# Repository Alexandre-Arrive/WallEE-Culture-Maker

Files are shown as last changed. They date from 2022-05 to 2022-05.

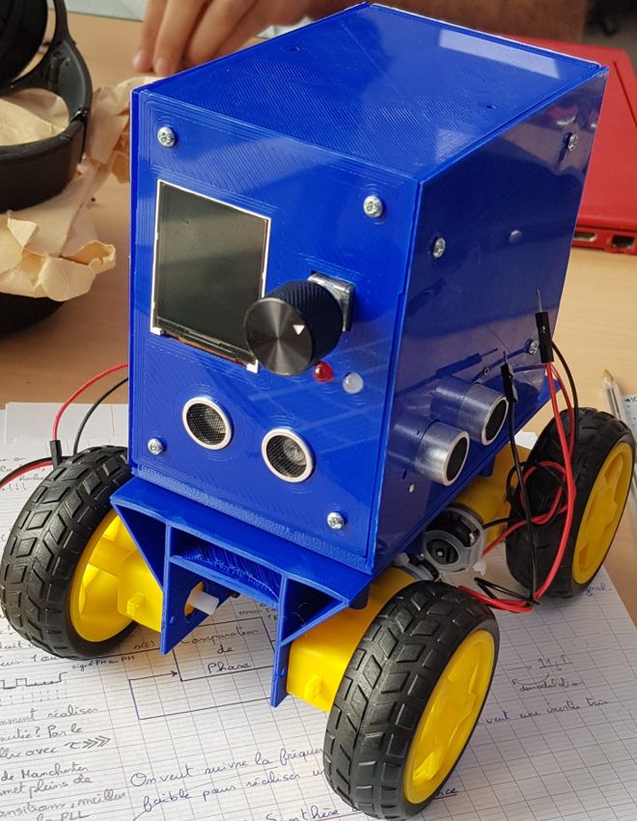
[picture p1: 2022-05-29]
wallee_outside_image.PNG

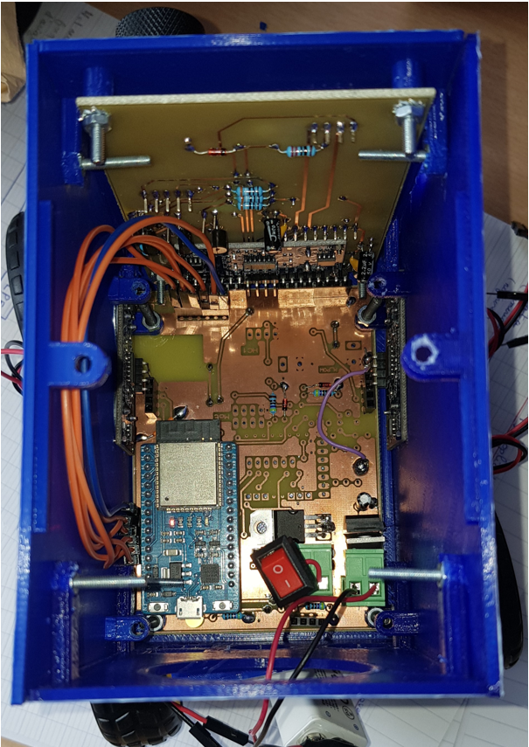
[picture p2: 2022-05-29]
wallee_inside_image.PNG

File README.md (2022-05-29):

Repositery du projet Culture Maker "WallEE".

Projet réalisé par Valentin Romero, Alexandre Arrivé, Mathieu Bernard
ENSEIRB-MATMECA, Département Electronique, 2022

Notre objectif était de concevoir un robot autonome capable détecter les obstacles dans son environnement, de se déplacer, de générer du son, et de proposer une interface utilisateur intuitive.

Le projet est donc composé d'une partie modélisation 3D, d'une partie circuit éléctronique, et d'une partie programmation.

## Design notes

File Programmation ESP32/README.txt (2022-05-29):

Ce dossier contient l'ensemble de nos codes permettant de vérifier le bon fonctionnement du robot.

La programmation de l'ESP32 est réalisée à l'aide de l'IDE Arduino.

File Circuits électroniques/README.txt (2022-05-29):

Ce dossier permet d'accéder aux différents circuits électroniques du projet.

Les deux fichiers principaux sont "PCB_central" et "PCB_face_avant".

Des images sont disponibles pour comprendre les circuits, sinon il sont ouvrables avec Proteus 8.

Les différentes parties disposent très souvent de fichier .doc qui permettent de détailler le fonctionnement des parties.

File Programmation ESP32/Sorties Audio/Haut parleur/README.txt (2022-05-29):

Ce code ne fonctionne que sur Arduino, il faut le porter sur l'ESP32.
Le problème vient de la lecture des données de la carte SD depuis l'ESP.

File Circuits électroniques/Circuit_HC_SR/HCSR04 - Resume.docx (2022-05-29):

# Résumé HCSR04 x4

I- HC-SR-04
1) La tension d’alimentation est 5V
2) La communication est 5V. On vient ajuster les tensions à l’aide d’un circuit.
3) Code + Circuit

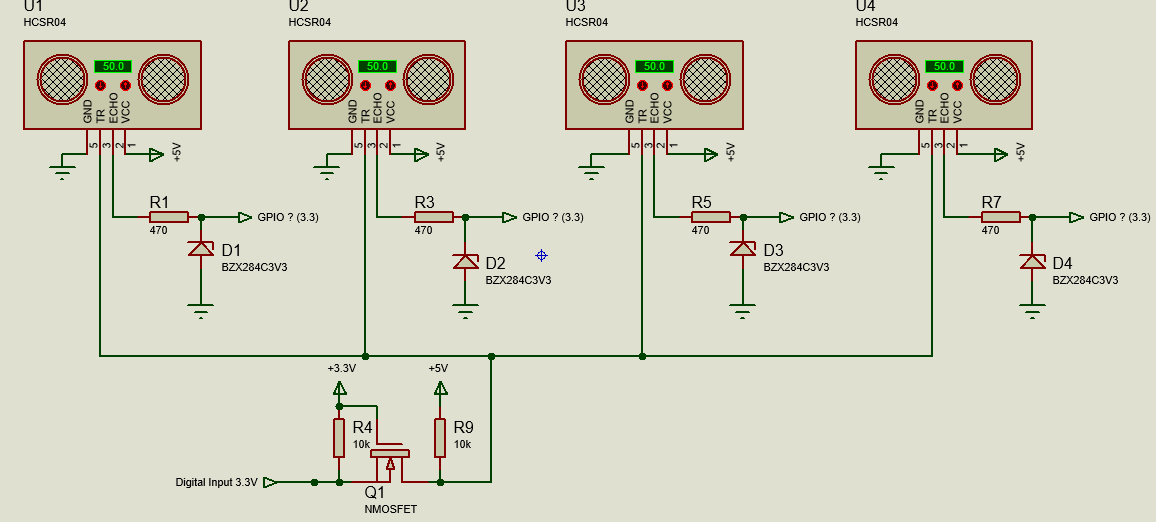
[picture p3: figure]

Code d’exemple « HC-SR-04-Wallee.ino » (avec fonctions générales)

Code propre pour utilisation sur programme final : « HC-SR-04-wallee-propre »

Code de temps d’éxecution « HCSR -temps-execution.ino » (programme de temps d’éxecution)

4) Principe de fonctionnement

Ecriture à l’état haut sur le trigger (commun à tous les capteurs) : émission 8 signaux ultrasons, on peut alors lire le capteur qui renvoi une durée d’impulsion (echo) qui détermine la distance parcourue.

Super article : https://www.gotronic.fr/pj2-hc-sr04-utilisation-avec-picaxe-1343.pdf

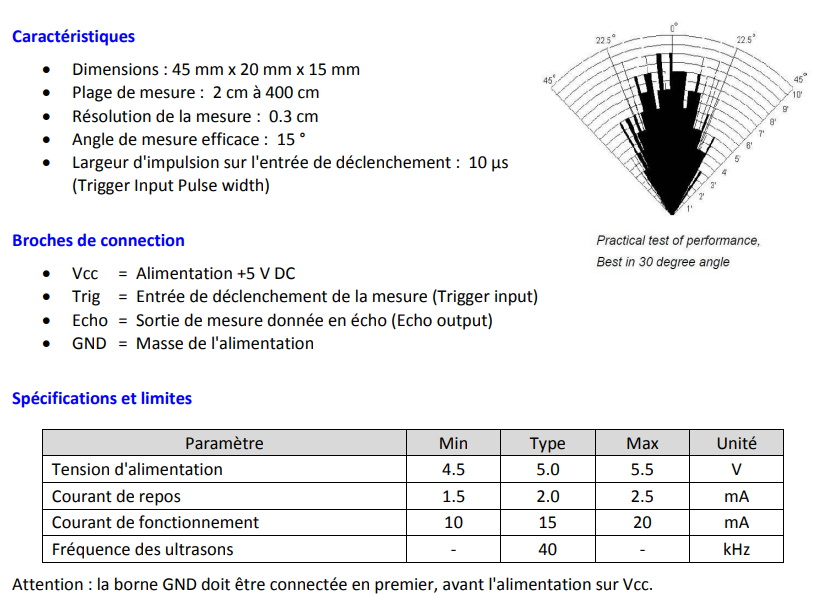
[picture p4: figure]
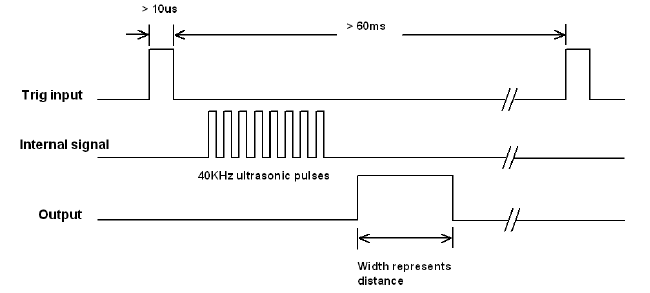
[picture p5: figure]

5) Pins

1- +5V | +5V
2- Trig | 26 (ESP) 5 (ARDUINO)
3- Echo | 35,34,39,36 (ESP) 6, 7, 8, 9 (ARDUINO)
4- GND | GND

Librairies à utiliser

#include <HCSR04.h>

Initialisation HC-SR04 x4(ARDUINO)

#define HC_trig 26 //On définit les broches des capteurs

#define HC1 35

#define HC2 34

#define HC3 39

#define HC4 36

HCSR04 hc_front(HC_trig, HC1); //On crée 4 objets correspondants aux capteurs

HCSR04 hc_right(HC_trig, HC2);

HCSR04 hc_left (HC_trig, HC3);

HCSR04 hc_back (HC_trig, HC4);

int erreur_ultrason=0; //Nombre d’erreur de mesure

int lim_err_HC=5; //Limite d'erreur avant reset des capteurs

int front=0; int right=1; int left=2; int back=3; //Rend intuitif l’appel des fonction: « ultrason_read(right) »

int measure_time=60; //Délai entre 2 mesures, recommandé à 60ms

int decharge_time=100; //Délai pour décharger les capteurs à l’initialisation/si trop d’erreur

Initialisation LED (ARDUINO)

#define led_verte 32

#define led_rouge 33

#define led_blanche 25

Fonctions à utiliser

Nom fonction | Rôle | Pire temps d’exécution (déconnecté) | Meilleur temps d’exécution
void Ultrason_Setup() | Setup des 4 capteurs | 120ms/120ms | 100ms
double Ultrason_Read(front/left/right/back) | Lecture distance 1 capteur | 199ms/1120ms | 1ms
int Ultrason_Indication(front/left/right/back) | Lecture indication 1 capteur | 199ms/1120ms | 1ms
double* Ultrason_All_Read() | Lecture distance 4 capteurs | 2318ms/4180ms | 184ms
int* Ultrason_All_Indication () | Lecture indication 4 capteur | 1517ms/4300ms | 184ms
void ultrason_ERREUR() | Réinitialise les capteurs + allume LED verte et rouge (commandé par Indication) | 125ms/125ms | 120ms

Fonction Setup - Fonction à utiliser – Fonction interne/peu probable à utiliser

NOTE IMPORTANTE –

Après avoir utilisé « Ultrason_All_Read() » il faut « delete distante » pour libérer l’espace mémoire

Après avoir utilisé « Ultrason_All_Indication » il faut « delete indication » pour libérer l’espace mémoire.

Il faut espacer deux mesures sur un même capteur de 60ms ! C’est la variable « measure_time ».

Les fonctions « Ultrason_Read » et « Ultrason_All_Read » ne peuvent pas lancer la fonction d’erreur automatiquement. Seules les fonctions « Ultrason_Indication » et « Ultrason_All_Indication » le font.

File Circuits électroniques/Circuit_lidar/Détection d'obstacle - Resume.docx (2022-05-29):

# Résumé détection d’obstacle

I- Lidar TF-Luna – I2C
1) La tension d’alimentation est 5V
2) La tension de communication est 3.3V – I2C (adresse 0x10)
3) Code + Circuit

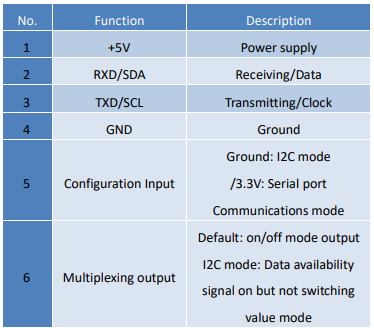
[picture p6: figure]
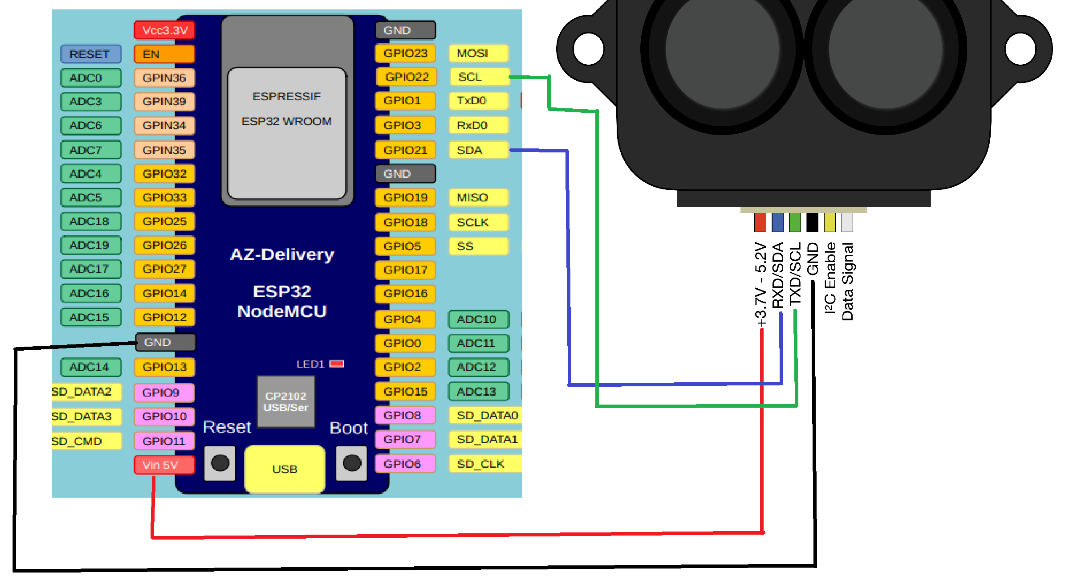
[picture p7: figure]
Issues with I2C communication for TFLuna LiDAR sensor from benewake: : r/esp32

Code d’exemple « LUNA-TEST-I2C.ino » (sans modification)

Code d’exemple « LUNA-I2C.ino » (avec fonctions générales)

Code de temps d’éxecution « LUNA-temps-execution.ino » (programme de temps d’éxecution)

4) Ecriture des fonctions pour le programme général

Initialisation

TFLI2C luna; //crée un objet TF-Luna appelé « luna »

int16_t tfAddr = TFL_DEF_ADR; // default I2C address – uint8_t

uint16_t tfFrame = TFL_DEF_FPS; // default frame rate

Setup

Wire.Begin() ;

luna.Soft_Reset(adr) // Reset, reboot et restart

if ( luna.Soft_Reset(adr) ) { LUNA_OK } //Détection d’erreur provenant du TF Luna

else luna.printStatus() ; //permet de connaitre l’état du TF Luna

luna.Get_Time( tfTime, adr); //Horloge du TF Luna sur un entier 16 bits

luna.Set_Frame_Rate( tfFrame, adr) ; //Envoie le nombre de frame/s, entier 16 bits

tfFrame = FPS_1 2 3 4 5 6 7 8 9 10 35 50 100 125 250 ou TFL_DEF_FPS=100

luna.Get_Frame_Rate( tfFrame, adr) ; // Lecture du nombre de frame/s

luna.Set_Trig_Mode(adr) ; //Mode trigger du Luna

luna.Set_Cont_Mode(adr) ; //Mode continu du Luna

luna.Save_Settings(adr) ; //Nécessaire après avoir changé le Frame-rate ou le Trig/Cont_Mode ou

l’adresse I2C

luna.Set_I2C_Addr(new adr, adr) ; //Permet de changer l’adresse I2C du Luna

Acquisition

luna.getData(dist, flux, temp, adr) ; //Lit le Luna et change la valeur de la distance, du flux et de la

température qui sont des entier signés 16 bits.

Il faut diviser la température reçue par 100.

La fonction renvoie 0 si la mesure s’est bien passé (si l’adresse I2C de retour est OK), on doit faire if( GetData){ affectation des mesures } Else { réagir au problème }

luna.getData(dist, adr) ; //Comme précédemment mais seulement pour la distance

5) Pins

1- +5V | +5V
2- SDA | 21
3- SCL | 22
4- GND | GND
5- Config I2C/Uart | GND
6- Multiplex output | rien

Librairies à utiliser

#include <Arduino.h> | #include <Wire.h> | #include <TFLI2C.h>

Initialisation TF-Luna

TFLI2C luna;

int16_t luna_addr = TFL_DEF_ADR;

uint16_t luna_frame = FPS_35;

int16_t luna_dist = 0 ;

int16_t luna_flux = 0 ;

int16_t luna_temp = 0 ;

Initialisation LED

#define led_verte 32

#define led_rouge 33

bool vert = HIGH;

Fonctions à utiliser

Nom fonction | Rôle | Pire temps d’exécution | Meilleur temps d’exécution
Luna_Setup() | Setup du TF-Luna | 42ms/62ms | 23ms
Luna_Measure() | Mesure de la distance, flux, et température | 23ms | 20ms/3ms
Luna_OK() | Inverse l’état de la LED verte | <1ms | <1ms
Luna_ERREUR() | Allume la LED rouge pendant 20ms | 21ms | 20ms

Fonction Setup - Fonction à utiliser – Fonction interne/peu probable à utiliser

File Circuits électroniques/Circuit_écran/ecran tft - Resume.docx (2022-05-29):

# Ecran tft

1) La tension d’alimentation est 5V
2) La communication s’effectue en 5V
3) Code + Circuit

Code d’exemple « ecran_tft_exemple »

Code propre pour utilisation sur programme final : « ecran_tft_Wallee »

Code de temps d’éxecution « tft-temps-execution.ino » (programme de temps d’éxecution)

4) Principe de fonctionnement

https://cdn-learn.adafruit.com/downloads/pdf/adafruit-gfx-graphics-library.pdf

5) Pins

1- VCC | 5V | 5V
2- GND | GND | 0V
3- CS | 10(Arduino) 4(ESP) | ->5V ?
4- RESET | 8(Arduino) 15(ESP) | ->5V ?
5- A0 | 9(Arduino) 17(ESP) | ->5V ?
6- SDA | 11(Arduino) 23(ESP) | ->5V ?
7- SCK | 13(Arduino) 18(ESP) | ->5V ?
8- LED | 3.3V | 3.3V
9- SD_CS | 4(Arduino) 21(ESP) à changer | ->5V ?
10- SD_MOSI | 11(Arduino) 23(ESP) | ->5V ?
11- SD_MISO | 12(Arduino) 19(ESP) | <-3.3V
12- SD_SCK | 13(Arduino) 18(ESP) | ->5V ?

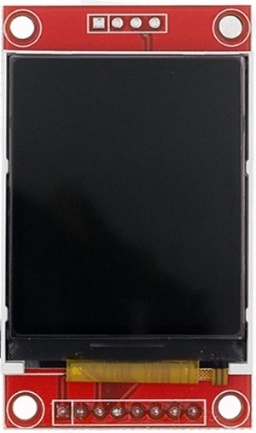
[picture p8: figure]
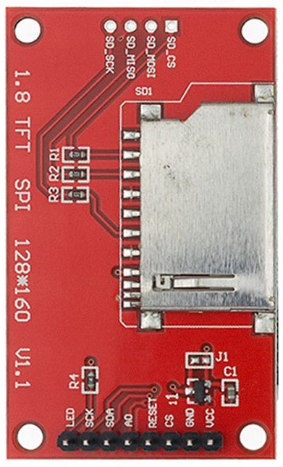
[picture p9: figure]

Initialisation

Nom fonction | Rôle | Pire temps d’exécution | Meilleur temps d’exécution
void Setup_Encodeur | Setup encodeur | 0ms | 0ms
void rotation_encodeur | Modifie les variables compteur et sens_rot | 0ms | 0ms
void bouton_on_off | Modifie la variable bouton | 0ms | 0ms
void encodeur::Setup() | Setup des pins, des variables | 0ms | 0ms
encodeur::encodeur() | Constructeur | --- | ---

Fonction Setup - Fonction à utiliser – Fonction interne/peu probable à utiliser- Fonction classes

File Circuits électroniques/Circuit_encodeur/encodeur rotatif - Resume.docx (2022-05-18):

# Encodeur rotatif

1) La tension d’alimentation est 5V ou 3.3V
2) La communication est Vcc=3.3V ici
3) Code + Circuit

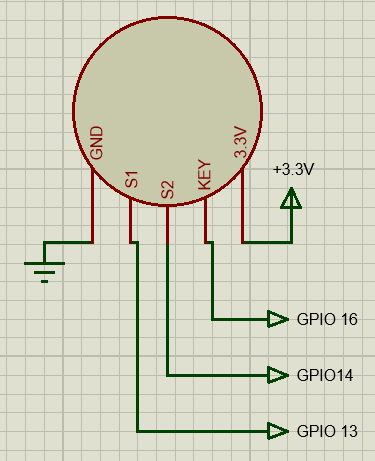
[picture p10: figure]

Code d’exemple « Rotary_encodeur_exemple »

Code propre pour utilisation sur programme final : « Rotary_encodeur_Wallee »

Code de temps d’éxecution « encodeur-temps-execution.ino » (programme de temps d’éxecution)

4) Principe de fonctionnement

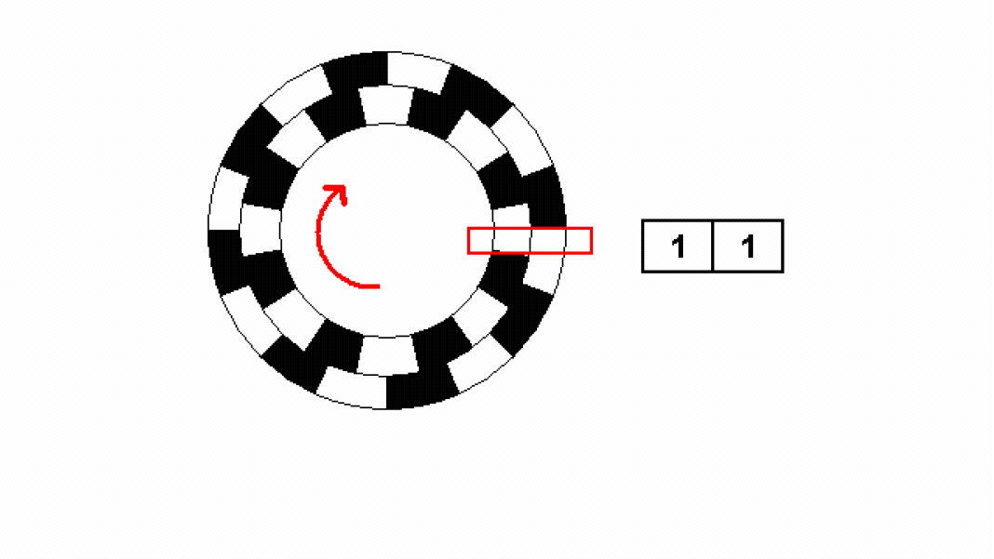
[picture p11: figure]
Rotary encoder rotation

https://retroetgeek.com/arduino/arduino-comment-utiliser-un-rotary-encoder-et-les-attachinterrupt/

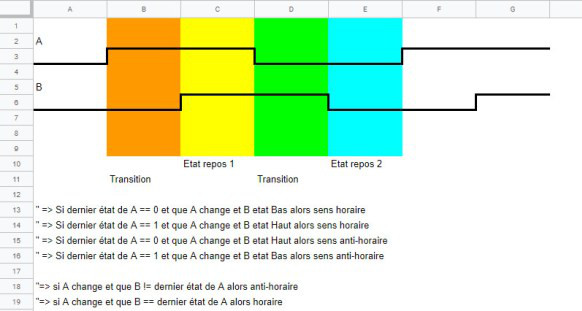
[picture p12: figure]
Sequence Rotary Encoder

5) Pins

1- GND | GND
2- S1 | 13 (ESP)
3- S2 | 14 (ESP)
4- KEY | 16 (ESP)
5- 5V | 3.3V (ESP)

Initialisation

#define pin_encodeur_1 13

#define pin_encodeur_2 14

#define pin_encodeur_key 16

class encodeur

public:

encodeur(); //Constructeur

void Setup(); //Setup

long unsigned temps; //NE PAS UTILISER

bool old_etat_s1; //NE PAS UTILISER

bool old_etat_bouton; //NE PAS UTILISER

bool etat_s1; //NE PAS UTILISER

bool etat_bouton; //NE PAS UTILISER

int compteur; //peut être négatif et positif

bool sens_rot; //0=gauche 1=droite

bool bouton; //0=non 1=oui

#define led_blanche 25

encodeur encod ;

Nom fonction | Rôle | Pire temps d’exécution | Meilleur temps d’exécution
void Setup_Encodeur | Setup encodeur | 0ms | 0ms
void rotation_encodeur | Modifie les variables compteur et sens_rot | 0ms | 0ms
void bouton_on_off | Modifie la variable bouton | 0ms | 0ms
void encodeur::Setup() | Setup des pins, des variables | 0ms | 0ms
encodeur::encodeur() | Constructeur | --- | ---

Fonction Setup - Fonction à utiliser – Fonction interne/peu probable à utiliser- Fonction classes

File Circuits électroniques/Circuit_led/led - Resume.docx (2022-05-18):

# LED Wallee

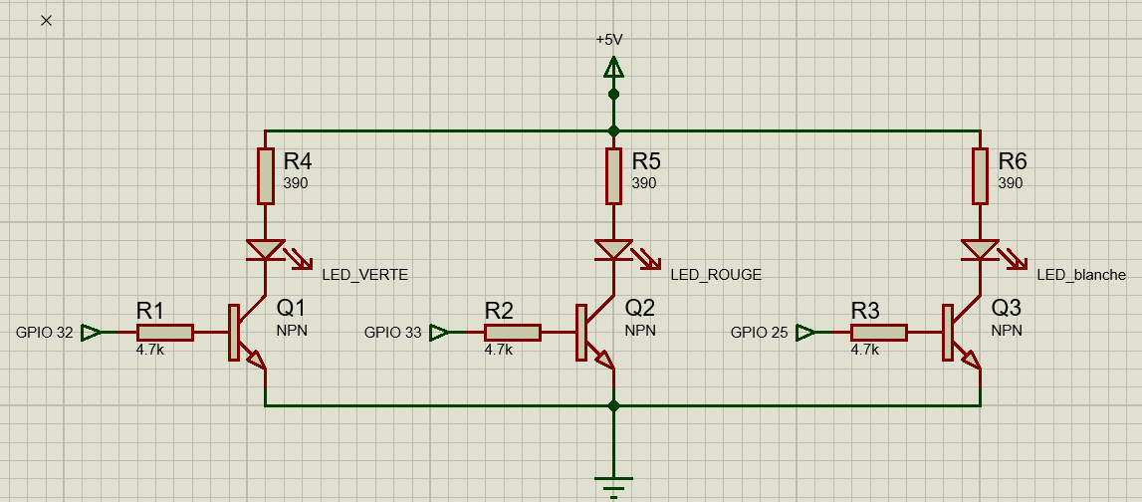
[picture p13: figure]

1- led_verte | 32(ESP)
2- led_rouge | 33(ESP)
3- led_blanche | 25(ESP)

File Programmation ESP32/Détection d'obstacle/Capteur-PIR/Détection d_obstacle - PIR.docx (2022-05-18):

# Résumé PIR

HC-SR501

1) La tension d’alimentation est de 5 à 12V (possiblement 20V). On utilise 5V
2) La tension de communication est 3.3V (vérifiée par oscilloscope)
3) Code + Circuit

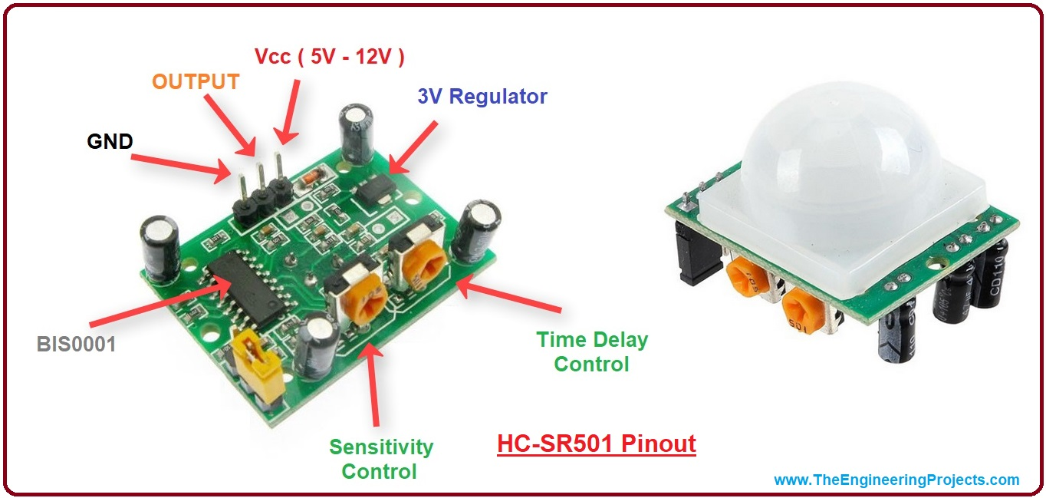
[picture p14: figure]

Code général « Capteur-PIR.ino » (fonctions principales + boucles de test)

Code de temps d'exécution « Capteur-PIR-temps-exec.ino » (programme de temps d'exécution)

Il est possible de modifier la distance de détection et le temps à l’état haut du trigger.

4) Pins

1- +POWER | +5V
2- H/L OUTPUT | 35 (ESP32)
3- GND | GND

Librairies à utiliser

Aucune

Initialisation des paramètres

#define PIR 35

bool sig_PIR = LOW; //Signal de détection de mouvement (format booléen)

Initialisation LED

#define led_verte 32

Fonctions à utiliser

Nom fonction | Rôle | Pire temps d’exécution | Meilleur temps d’exécution
void PIR_Setup() | Setup du capteur PIR | 0,00 ms | 0,00 ms
bool PIR_Measure() | Relevé ponctuel d’un mouvement en cours | 21,00 ms | 20,00 ms

Fonction Setup - Fonction à utiliser – Fonction interne/peu probable à utiliser

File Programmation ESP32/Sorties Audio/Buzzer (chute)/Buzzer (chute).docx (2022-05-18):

Résumé Buzzer

RS 7800712

1) La tension d’alimentation est de 3.3 à 8V. On utilise 5V sur un driver MOS + Charge.

-> Courant d’alimentation < 40 mA et Résistance interne de 47 ± 5 ohms

2) Aucune communication requise.
3) Code + Circuit

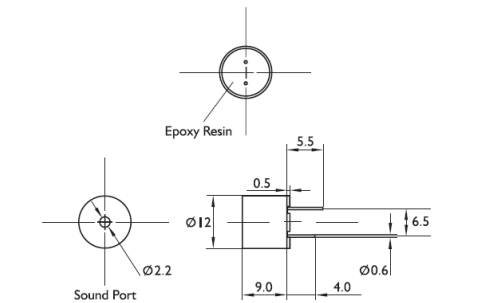
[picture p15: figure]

Code général « Buzzer.ino » (fonctions principales + boucle de test)

Code de temps d'exécution « Buzzer-temps-exec.ino » (programme de temps d'exécution)

Il est possible de modifier la mélodie jouée par le buzzer lors d’une chute.

4) Pins

1- +POWER (pâte longue) | +5V
2- GND (pâte courte) | GND

Librairies à utiliser

Tone32.h | pitches.h

Initialisation des paramètres

#include “pitches.h” //Librairie des notes jouables par le buzzer
#include “Tone32.h” //Librairie des fonctions tone pour l'ESP32
#define buzzer 27 //Pin du driver de buzzer
#define chan_PWM 9 //Canal PWM de la pin "buzzer"
#define note NOTE_C4 //Note élémentaire du buzzer (plus de valeurs dans “pitches.h”)

int son [] = { note, 2*note, note, 2*note } ; //Mélodie à jouer par le buzzer, basée sur la note originale
int duree [] = { 250, 250, 250, 250 } ; //Durée de lecture de chaque note (< ou = à 250)
int nb_notes = 4 ; //Nombre de notes dans la mélodie

Initialisation LED

#define led_rouge 33 //Pin de la LED rouge

Fonctions à utiliser

Nom fonction | Rôle | Pire temps d’exécution | Meilleur temps d’exécution
void Buzzer_Setup() | Setup du buzzer | 0,00 ms | 0,00 ms
void Buzzer_Chute() | Joue un son prédéterminé en cas de chute du robot | 3000,00 ms | 3000,00 ms

Fonction Setup - Fonction à utiliser – Fonction interne/peu probable à utiliser

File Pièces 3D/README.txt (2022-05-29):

Ce dossier contient l'ensemble des pièces 3D constituant le robot.

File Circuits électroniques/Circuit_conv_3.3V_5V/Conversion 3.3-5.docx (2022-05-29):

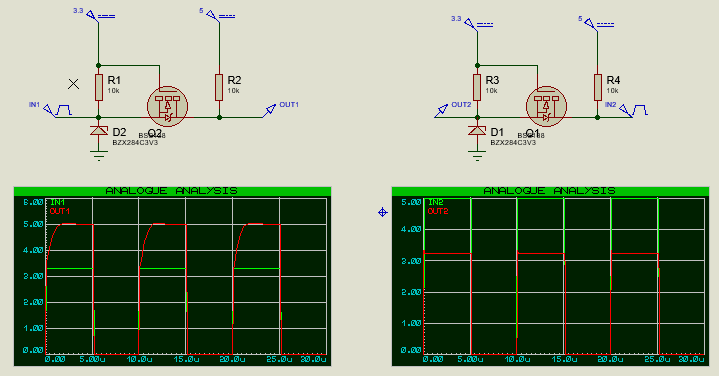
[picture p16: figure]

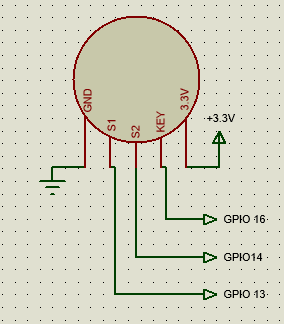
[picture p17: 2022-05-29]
Circuits électroniques/Circuit_encodeur/image_encod_circuit.PNG

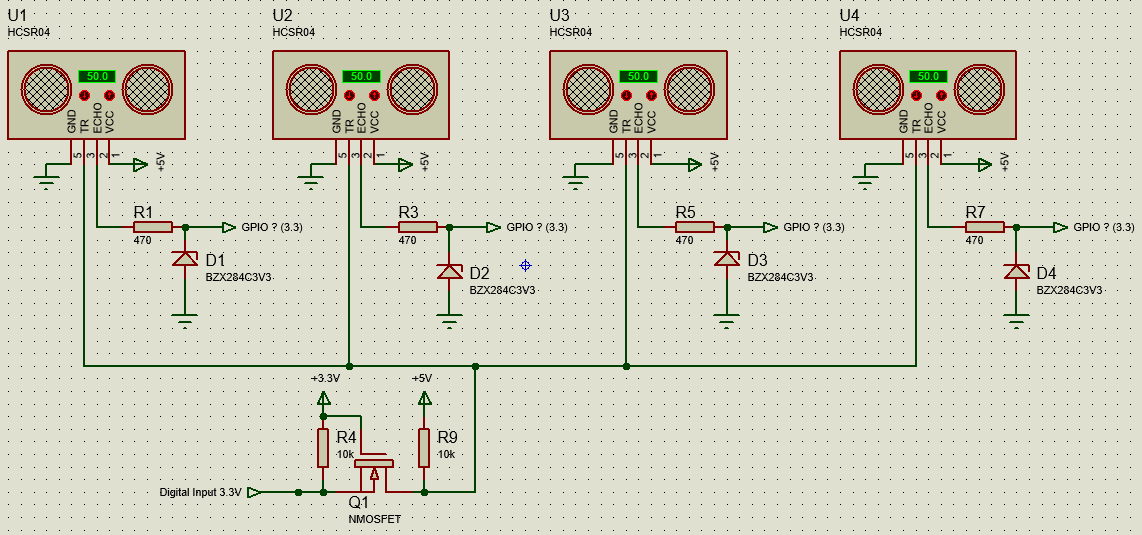
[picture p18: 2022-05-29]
Circuits électroniques/Circuit_HC_SR/image_HC_SR_circuit.PNG

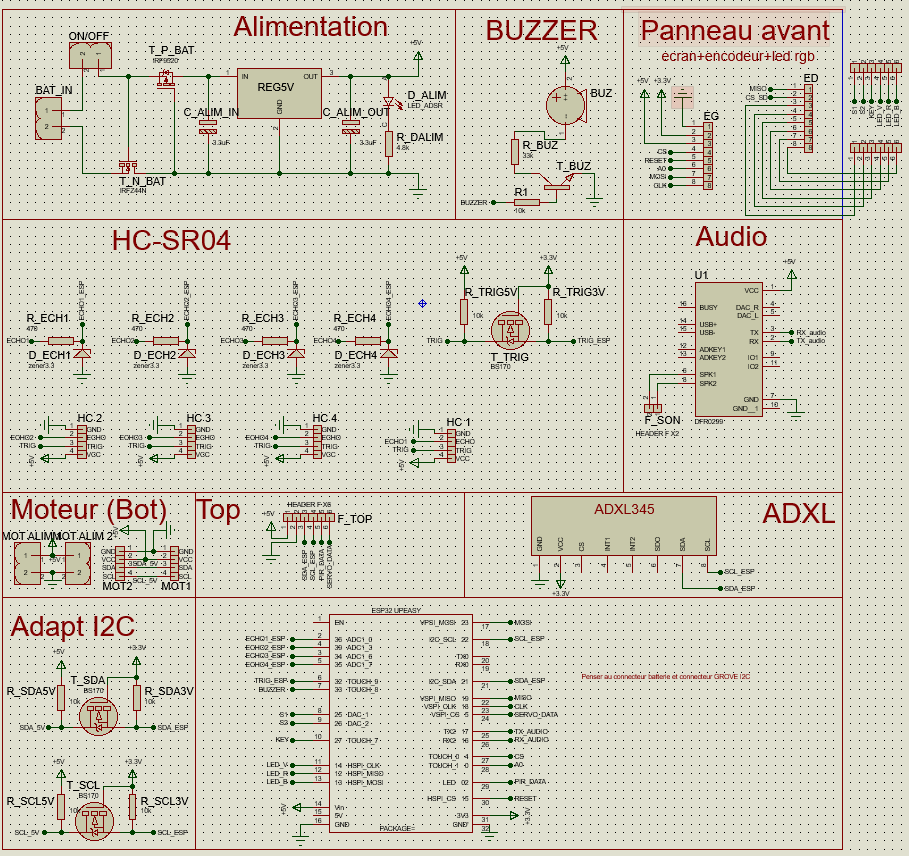
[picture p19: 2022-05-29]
Circuits électroniques/PCB_central/image_main_circuit.PNG

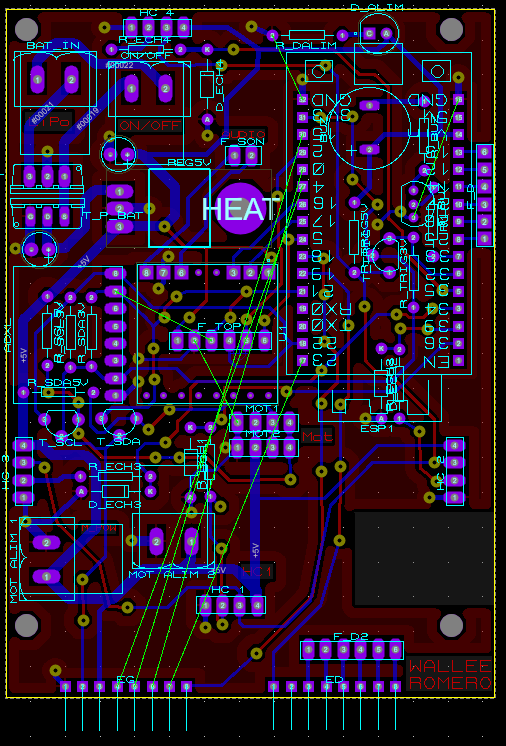
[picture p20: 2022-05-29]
Circuits électroniques/PCB_central/image_main_pcb.PNG

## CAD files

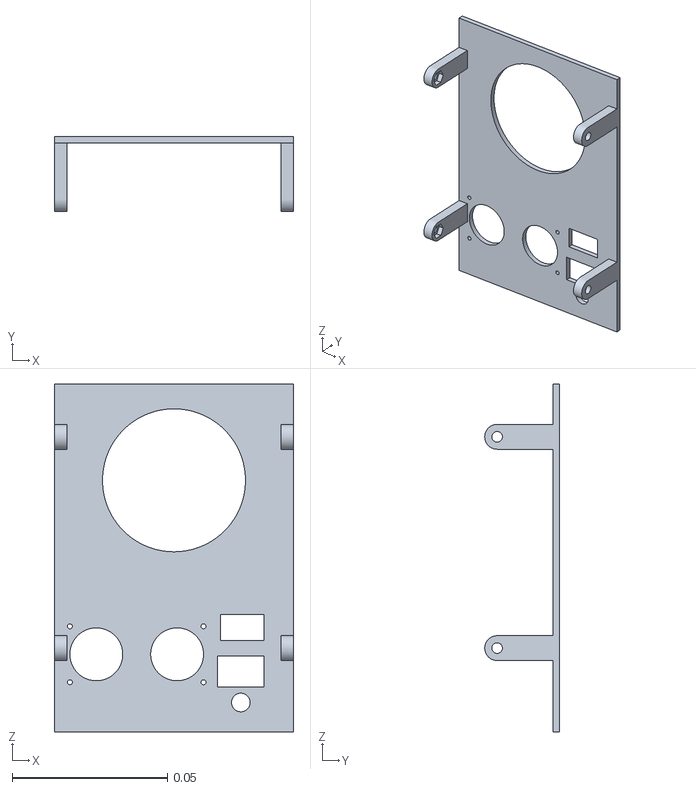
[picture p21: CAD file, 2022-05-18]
Pièces 3D/Plaque Face Arrière.stl
0.077 x 0.024 x 0.112

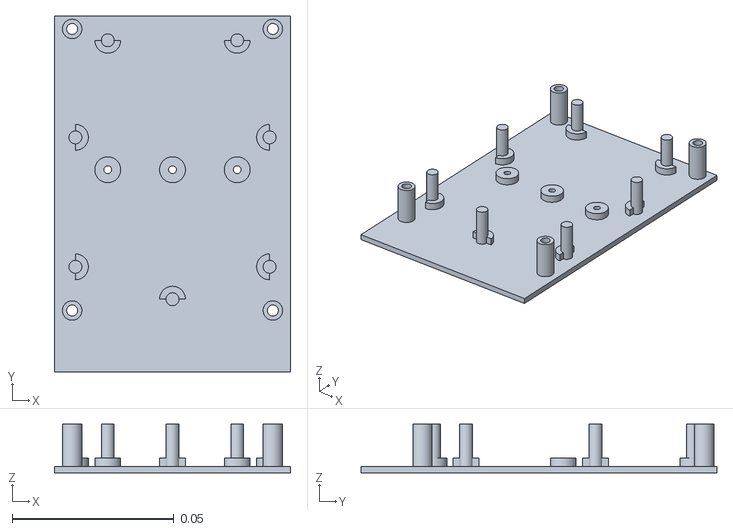
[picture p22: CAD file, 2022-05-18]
Pièces 3D/Support Drivers.stl
0.073 x 0.11 x 0.015

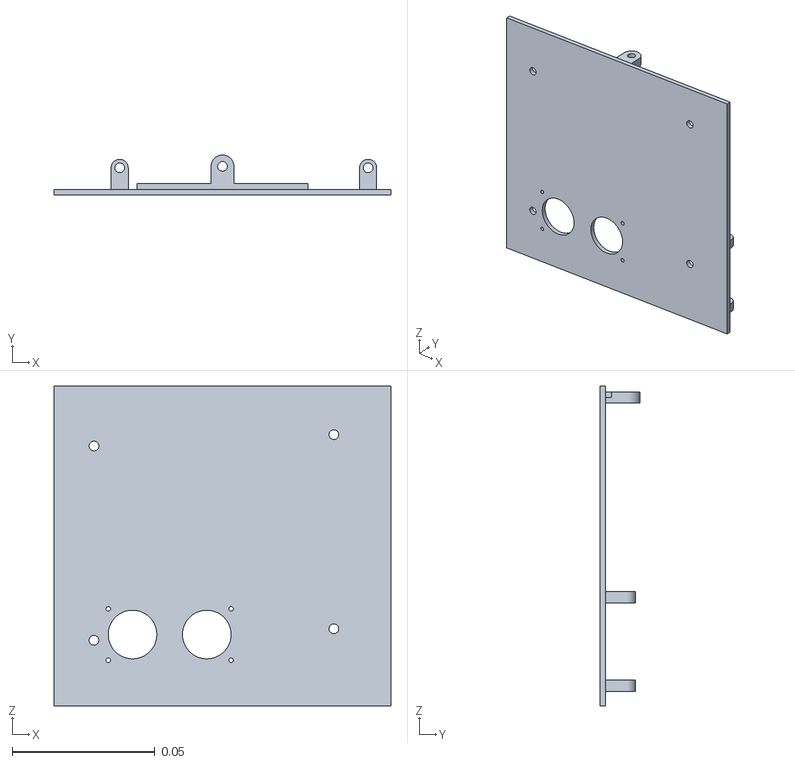
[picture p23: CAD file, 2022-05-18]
Pièces 3D/Plaque Latérale Gauche.stl
0.118 x 0.014 x 0.112

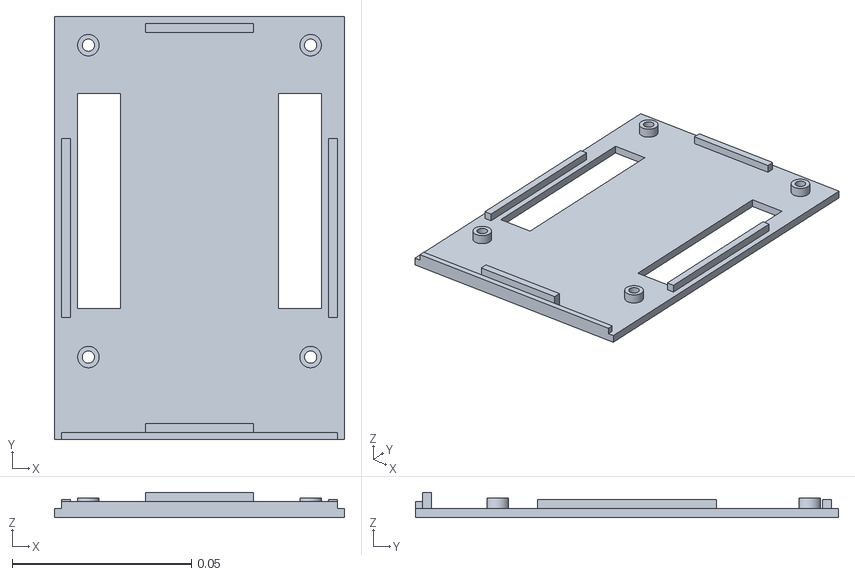
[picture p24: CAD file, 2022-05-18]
Pièces 3D/Plaque Principale.stl
0.081 x 0.118 x 0.007

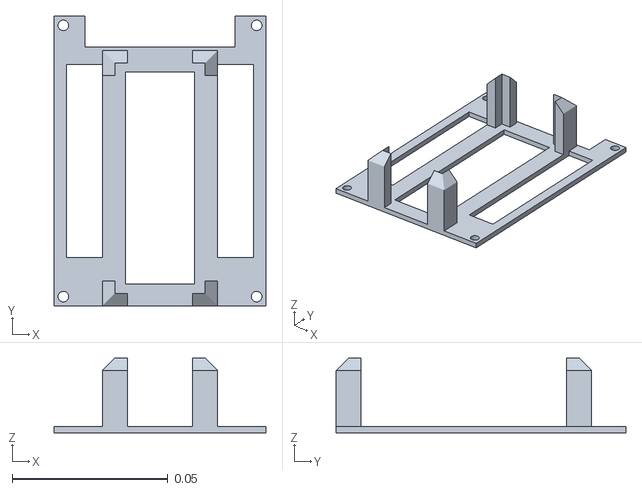
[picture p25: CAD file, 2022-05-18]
Pièces 3D/Support Batterie.stl
0.068 x 0.093 x 0.024

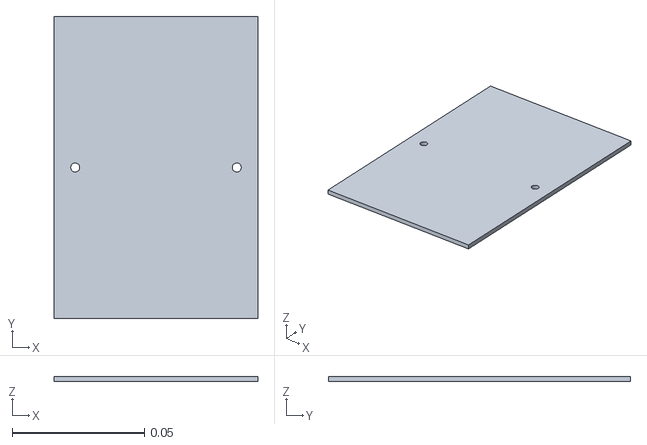
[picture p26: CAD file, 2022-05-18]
Pièces 3D/Plaque Supérieure.stl
0.077 x 0.114 x 0.002

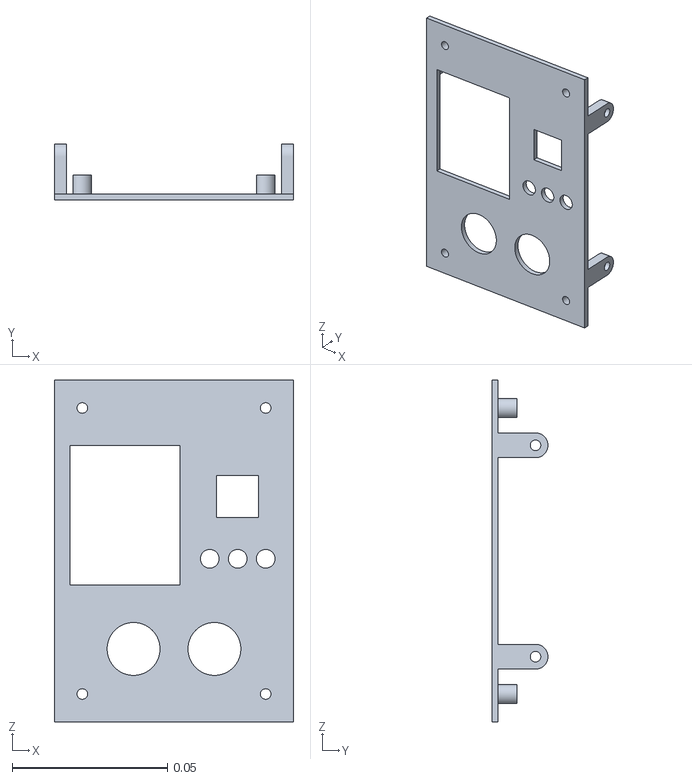
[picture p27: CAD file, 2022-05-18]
Pièces 3D/Plaque Face Avant.stl
0.077 x 0.018 x 0.11

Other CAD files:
Pièces 3D/Plaque Latérale Droite.stl

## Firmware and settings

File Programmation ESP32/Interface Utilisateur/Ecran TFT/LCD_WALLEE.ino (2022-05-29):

#include <Adafruit_GFX.h>    // include Adafruit graphics library
#include <Adafruit_ST7735.h> // include Adafruit ST7735 display library
#include <SPI.h>             // include Arduino SPI library
#include <SD.h>              // include Arduino SD library
 
////////////////TFT initialisation//////////////////////////////////
#define TFT_RST  15//8   // (RESET) reset line (-1 if not used)
#define TFT_CS   4//10  // (CS) tft chip select
#define TFT_DC   17//9   // (A0) tft data/command
#define TFT_MOSI 23//11  // (SDA) tft mosi
#define TFT_SCLK 18//13  // (SCK) tft clk
#define CS_SD    21//4   // SD chip select

Adafruit_ST7735 tft = Adafruit_ST7735(TFT_CS, TFT_DC, TFT_RST);

#define led_verte 32//A0
#define led_rouge 33//A1
#define led_blanche 25//A2

// Color definitions
#define BLACK 0x0000
#define BLUE 0x001F
#define RED 0xF800
#define GREEN 0x37E6//0x07E0
#define CYAN 0x07FF
#define MAGENTA 0xF81F
#define YELLOW 0xFFE0
#define WHITE 0xFFFF

void TFT_init(){
  digitalWrite(led_blanche, HIGH);
  pinMode(TFT_CS, OUTPUT);
  digitalWrite(TFT_CS, HIGH);  
  tft.initR(INITR_BLACKTAB);
  tft.fillScreen(ST77XX_BLACK);
  digitalWrite(led_blanche, LOW);
}

void SD_init(){
  digitalWrite(led_blanche, HIGH);
  Serial.println(""); Serial.print("Initializing SD card ");
  if (!SD.begin(CS_SD)) {
    Serial.println("FAILED");
    digitalWrite(led_rouge, HIGH);
  }
  else{
    Serial.println("OK. Every available file :");
    File root = SD.open("/");  // open SD card main root
    printDirectory(root, 0);   // print all files names and sizes
    root.close();              // close the opened root
  }
  digitalWrite(led_blanche, LOW);
}

void setup(void) {
  Serial.begin(115200);
  pinMode(led_verte, OUTPUT);
  pinMode(led_rouge, OUTPUT);
  pinMode(led_blanche, OUTPUT);
    
  TFT_init();
  SD_init();
}
 
void loop() {
  Serial.println("");
  bmpDraw("/mod1G.bmp",0,0);
  tft.drawRect(12,114, 104,34,BLACK);
  tft.drawRect(13,115, 102,32,BLACK);
  tft.drawRect(14,116, 100,30,BLACK);
  delay(250);
  for(int i=0; i<=10; i++){
    tft.fillRect(14,116, 10*i,30, GREEN);
    tft.drawRect(14,116, 100,30,BLACK);
    delay(250);
  }
  delay(500);
  tft.fillScreen(ST77XX_BLACK);
  
  long int t=millis();
  draw_mode(1, BLUE);
  draw_mode(2, BLUE);
  draw_mode(3, BLUE);
  draw_mode(4, BLUE);
  Serial.println(millis()-t);
  delay(500);
  draw_mode(1, GREEN);
  delay(500);
  draw_mode(1, BLUE);
  draw_mode(2, GREEN);
  delay(500);
  draw_mode(2, BLUE);
  draw_mode(3, GREEN);
  delay(500);
  draw_mode(3, BLUE);
  draw_mode(4, GREEN);
  delay(500);
  
  //TEST 0
  Serial.println("");
  t=millis();
  tft.fillScreen(ST77XX_BLACK);
  Serial.println(millis()-t);
  
  //TEST01
  t=millis();
  tft.fillRect(14, 5 , 99, 5+32, ST77XX_RED);
  tft.drawRect(14, 5 , 99, 5+32, ST77XX_BLUE);
  
  tft.fillRect(14, 43 , 99, 43+32, ST77XX_RED);
  tft.drawRect(14, 43 , 99, 43+32, ST77XX_BLUE);
  
  tft.fillRect(14, 83 , 99, 83+32, ST77XX_RED);
  tft.drawRect(14, 83 , 99, 83+32, ST77XX_BLUE);
  
  tft.fillRect(14, 121 , 99, 121+32, ST77XX_RED);
  tft.drawRect(14, 121 , 99, 121+32, ST77XX_BLUE);
  Serial.println(millis()-t);
  delay(2500); 
  //TEST 1
  bmpDraw("Wallee.bmp",0,0);
  delay(500);
  bmpDraw("MOD1G.bmp",14,5);
  delay(1000);
  bmpDraw("MOD2G.bmp",14,43);
  delay(1000);
  bmpDraw("MOD3G.bmp",14,83);
  delay(1000);
  bmpDraw("MOD4G.bmp",14,121);
  delay(1000);
  
  //TEST 2
  bmpDraw("menu.bmp",0,0);
  delay(1000);
  bmpDraw("MOD1B.bmp",14,5);
  bmpDraw("MOD2G.bmp",14,43);
  delay(1000);
  bmpDraw("MOD2B.bmp",14,43);
  bmpDraw("MOD3G.bmp",14,83);
  delay(1000);
  bmpDraw("MOD3B.bmp",14,83);
  bmpDraw("MOD4G.bmp",14,121);
  delay(1000);
  
}

void draw_mode(int numero, int couleur){
  int y1=4;
  int y2=43;
  int y3=82;
  int y4=121;
  tft.setTextSize(2);
  if(couleur==GREEN){ tft.setTextColor(BLACK); }
  else {              tft.setTextColor(WHITE); }
  switch(numero){
    case 1:
      tft.setCursor(29,y1+11);
      tft.fillRoundRect(14,y1,  100,37,  10, couleur);
      tft.drawRoundRect(14,y1,  100,37,  10, WHITE);
      tft.print("Mode 1");
      break;
    case 2:
      tft.setCursor(29,y2+11); //16+38=54   
      tft.fillRoundRect(14,y2,  100,37,  10, couleur);
      tft.drawRoundRect(14,y2,  100,37,  10, WHITE);
      tft.print("Mode 2");      
      break;  
    case 3:
      tft.setCursor(29,y3+11);
      tft.fillRoundRect(14,y3,  100,37,  10, couleur);
      tft.drawRoundRect(14,y3,  100,37,  10, WHITE);
      tft.print("Mode 3");      
      break;  
    case 4:
      tft.setCursor(29,y4+11);
      tft.fillRoundRect(14,y4,  100,37,  10, couleur);
      tft.drawRoundRect(14,y4,  100,37,  10, WHITE);
      tft.print("Mode 4");      
      break;  
  }
}

 
// This function opens a Windows Bitmap (BMP) file and
// displays it at the given coordinates.  It's sped up
// by reading many pixels worth of data at a time
// (rather than pixel by pixel).  Increasing the buffer
// size takes more of the Arduino's precious RAM but
// makes loading a little faster.  20 pixels seems a
// good balance.
 
#define BUFFPIXEL 50
 
void bmpDraw(char *filename, uint8_t x, uint16_t y) {
 
  File     bmpFile;
  int      bmpWidth, bmpHeight;   // W+H in pixels
  uint8_t  bmpDepth;              // Bit depth (currently must be 24)
  uint32_t bmpImageoffset;        // Start of image data in file
  uint32_t rowSize;               // Not always = bmpWidth; may have padding
  uint8_t  sdbuffer[3*BUFFPIXEL]; // pixel buffer (R+G+B per pixel)
  uint8_t  buffidx = sizeof(sdbuffer); // Current position in sdbuffer
  boolean  goodBmp = false;       // Set to true on valid header parse
  boolean  flip    = true;        // BMP is stored bottom-to-top
  int      w, h, row, col;
  uint8_t  r, g, b;
  uint32_t pos = 0, startTime = millis();
 
  if((x >= tft.width()) || (y >= tft.height())) return;
 
  Serial.println();
  Serial.print(F("Loading image '"));
  Serial.print(filename);
  Serial.println('\'');
 
  // Open requested file on SD card
  if ((bmpFile = SD.open(filename)) == NULL) {
    Serial.print(F("File not found"));
    return;
  }
 
  // Parse BMP header
  if(read16(bmpFile) == 0x4D42) { // BMP signature
    Serial.print(F("File size: ")); Serial.println(read32(bmpFile));
    (void)read32(bmpFile); // Read & ignore creator bytes
    bmpImageoffset = read32(bmpFile); // Start of image data
    Serial.print(F("Image Offset: ")); Serial.println(bmpImageoffset, DEC);
    // Read DIB header
    Serial.print(F("Header size: ")); Serial.println(read32(bmpFile));
    bmpWidth  = read32(bmpFile);
    bmpHeight = read32(bmpFile);
    if(read16(bmpFile) == 1) { // # planes -- must be '1'
      bmpDepth = read16(bmpFile); // bits per pixel
      Serial.print(F("Bit Depth: ")); Serial.println(bmpDepth);
      if((bmpDepth == 24) && (read32(bmpFile) == 0)) { // 0 = uncompressed
 
        goodBmp = true; // Supported BMP format -- proceed!
        Serial.print(F("Image size: "));
        Serial.print(bmpWidth);
        Serial.print('x');
        Serial.println(bmpHeight);
 
        // BMP rows are padded (if needed) to 4-byte boundary
        rowSize = (bmpWidth * 3 + 3) & ~3;
 
        // If bmpHeight is negative, image is in top-down order.
        // This is not canon but has been observed in the wild.
        if(bmpHeight < 0) {
          bmpHeight = -bmpHeight;
          flip      = false;
        }
 
        // Crop area to be loaded
        w = bmpWidth;
        h = bmpHeight;
        if((x+w-1) >= tft.width())  w = tft.width()  - x;
        if((y+h-1) >= tft.height()) h = tft.height() - y;
 
        // Set TFT address window to clipped image bounds
        tft.startWrite();
        tft.setAddrWindow(x, y, w, h);
 
        for (row=0; row<h; row++) { // For each scanline...
 
          // Seek to start of scan line.  It might seem labor-
          // intensive to be doing this on every line, but this
          // method covers a lot of gritty details like cropping
          // and scanline padding.  Also, the seek only takes
          // place if the file position actually needs to change
          // (avoids a lot of cluster math in SD library).
          if(flip) // Bitmap is stored bottom-to-top order (normal BMP)
            pos = bmpImageoffset + (bmpHeight - 1 - row) * rowSize;
          else     // Bitmap is stored top-to-bottom
            pos = bmpImageoffset + row * rowSize;
          if(bmpFile.position() != pos) { // Need seek?
            tft.endWrite();
            bmpFile.seek(pos);
            buffidx = sizeof(sdbuffer); // Force buffer reload
          }
 
          for (col=0; col<w; col++) { // For each pixel...
            // Time to read more pixel data?
            if (buffidx >= sizeof(sdbuffer)) { // Indeed
              bmpFile.read(sdbuffer, sizeof(sdbuffer));
              buffidx = 0; // Set index to beginning
              tft.startWrite();
            }
 
            // Convert pixel from BMP to TFT format, push to display
            b = sdbuffer[buffidx++];
            g = sdbuffer[buffidx++];
            r = sdbuffer[buffidx++];
            tft.pushColor(tft.color565(r,g,b));
          } // end pixel
        } // end scanline
        tft.endWrite();
        Serial.print(F("Loaded in "));
        Serial.print(millis() - startTime);
        Serial.println(" ms");
      } // end goodBmp
    }
  }
 
  bmpFile.close();
  if(!goodBmp) Serial.println(F("BMP format not recognized."));
}
 
 
// These read 16- and 32-bit types from the SD card file.
// BMP data is stored little-endian, Arduino is little-endian too.
// May need to reverse subscript order if porting elsewhere.
 
uint16_t read16(File f) {
  uint16_t result;
  ((uint8_t *)&result)[0] = f.read(); // LSB
  ((uint8_t *)&result)[1] = f.read(); // MSB
  return result;
}
 
uint32_t read32(File f) {
  uint32_t result;
  ((uint8_t *)&result)[0] = f.read(); // LSB
  ((uint8_t *)&result)[1] = f.read();
  ((uint8_t *)&result)[2] = f.read();
  ((uint8_t *)&result)[3] = f.read(); // MSB
  return result;
}
 
 
void printDirectory(File dir, int numTabs) {
  while (true) {
 
    File entry =  dir.openNextFile();
    if (! entry) {
      // no more files
      break;
    }
    for (uint8_t i = 0; i < numTabs; i++) {
      Serial.print('\t');
    }
    Serial.print(entry.name());
    if (entry.isDirectory()) {
      Serial.println("/");
      printDirectory(entry, numTabs + 1);
    } else {
      // files have sizes, directories do not
      Serial.print("\t\t");
      Serial.println(entry.size(), DEC);
    }
    entry.close();
  }
}
 

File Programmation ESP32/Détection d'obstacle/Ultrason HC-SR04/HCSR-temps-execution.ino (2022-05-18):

#include <HCSR04.h>

//////Initialisation des LEDs/////////
#define led_verte 32
#define led_rouge 33
#define led_blanche 25
//////////////////////////////////////

//////Initialisation ultrasons//////////
#define HC_trig 26                                 
#define HC1 35
#define HC2 34
#define HC3 39
#define HC4 36
HCSR04 hc_front(HC_trig, HC1);                     //(trig, echo)
HCSR04 hc_right(HC_trig, HC2); 
HCSR04 hc_left (HC_trig, HC3); 
HCSR04 hc_back (HC_trig, HC4); 
int erreur_ultrason=0;                             //compteur d'erreur de la lecture ultrason. Incrémente lorsque mesure 0.
int lim_err_HC=5;                                  //limite d'erreur avant reset des capteurs
int front=0; int right=1; int left=2; int back=3; 
int measure_time=60;
int decharge_time=100;
////////////////////////////////////////

/////Initialisation temps de mesure///
double t1=0, t2=0;
double tab[10]={0,0,0,0,0,0,0,0,0,0};
//////////////////////////////////////

//////Setup Ultrasons//////////
void Ultrason_Setup()
{
  if(erreur_ultrason==0){
    digitalWrite(led_blanche, HIGH);
  }
  pinMode(HC_trig, OUTPUT); digitalWrite(HC_trig, LOW);
  pinMode(HC1, OUTPUT);  digitalWrite(HC1, LOW);
  pinMode(HC2, OUTPUT);  digitalWrite(HC2, LOW);
  pinMode(HC3, OUTPUT);  digitalWrite(HC3, LOW);
  pinMode(HC4, OUTPUT);  digitalWrite(HC4, LOW);
  delay(decharge_time); //Temps de décharge des condensateurs des HC, préconisé à 100ms
  pinMode(HC1, INPUT);   pinMode(HC2, INPUT);   pinMode(HC3, INPUT);   pinMode(HC4, INPUT);
  Serial.println("Ultrason Setup Done");
  digitalWrite(led_blanche, LOW);
}
//////////////////////////////////////

void setup()
{ 
  Serial.begin(115200); 
  pinMode(led_verte, OUTPUT);
  pinMode(led_rouge, OUTPUT);
  pinMode(led_blanche, OUTPUT);

  ///////MESURE Ultrason_Setup/////////
  for(int i=0; i<10; i++){
    t1=millis();
    Ultrason_Setup(); 
    t2=millis();
    tab[i]=(double)(t2-t1);
  }
    
  Serial.println("");Serial.println("");Serial.println("");Serial.println("");
  Serial.print("Les 10 temps d'execution de Ultrason_Setup :");
  for(int i=0; i<10; i++){
    Serial.print(tab[i]); Serial.print("   ");
    tab[i]=(double)(t2-t1);
  }
  Serial.println("");Serial.println("");Serial.println("");Serial.println("");
  ///////////////////////////

  ///////MESURE Ultrason_Measure/////////
  for(int j=0; j<4; j++){
    for(int i=0; i<10; i++){
      t1=millis();
      double x = Ultrason_Read(j);
      t2=millis();
      delay(measure_time);
      tab[i]=(double)(t2-t1);
    }
   
    Serial.print("Les 10 temps d'execution de Ultrason_Read capteur numero");Serial.println(j);
    for(int i=0; i<10; i++){
      Serial.print(tab[i]); Serial.print("   ");
      tab[i]=(double)(t2-t1);
    }
    Serial.println("");
  }
  Serial.println("");Serial.println("");Serial.println("");Serial.println("");
  ///////////////////////////

    ///////MESURE Ultrason_indication/////////
  for(int j=0; j<4; j++){
    for(int i=0; i<10; i++){
      t1=millis();
      int y=Ultrason_Indication(j);
      t2=millis();
      delay(measure_time);
      tab[i]=(double)(t2-t1);
    }
   
    Serial.print("Les 10 temps d'execution de Ultrason_Indication capteur numero");Serial.println(j);
    for(int i=0; i<10; i++){
      Serial.print(tab[i]); Serial.print("   ");
      tab[i]=(double)(t2-t1);
    }
    Serial.println("");
  }
  Serial.println("");Serial.println("");Serial.println("");Serial.println("");
  ///////////////////////////


  ///////MESURE Ultrason_All_Read/////////
    for(int i=0; i<10; i++){
      t1=millis();
      double* test3=Ultrason_All_Read();
      t2=millis();
      delay(measure_time);
      delete test3;
      tab[i]=(double)(t2-t1);
    }
    
    Serial.println("Les 10 temps d'execution de Ultrason_All_Read");
    for(int i=0; i<10; i++){
      Serial.print(tab[i]); Serial.print("   ");
      tab[i]=(double)(t2-t1);
    }
    
  Serial.println("");Serial.println("");Serial.println("");Serial.println("");
  ///////////////////////////

  ///////MESURE Ultrason_All_Indication/////////
    for(int i=0; i<10; i++){
      t1=millis();
      int* test4=Ultrason_All_Indication();
      t2=millis();
      delay(measure_time);
      delete test4;
      tab[i]=(double)(t2-t1);
    }
    
    Serial.println("Les 10 temps d'execution de Ultrason_All_Indication");
    for(int i=0; i<10; i++){
      Serial.print(tab[i]); Serial.print("   ");
      tab[i]=(double)(t2-t1);
    }
   
  Serial.println("");Serial.println("");Serial.println("");Serial.println("");
  ///////////////////////////

  ///////MESURE ultrason_ERREUR/////////
    for(int i=0; i<10; i++){
      t1=millis();
      ultrason_ERREUR();
      t2=millis();
      delay(measure_time);
      tab[i]=(double)(t2-t1);
    }
    
    Serial.println("Les 10 temps d'execution de ultrason_ERREUR");
    for(int i=0; i<10; i++){
      Serial.print(tab[i]); Serial.print("   ");
      tab[i]=(double)(t2-t1);
    }
    
  Serial.println("");Serial.println("");Serial.println("");Serial.println("");
  ///////////////////////////

}

void loop()
{
}

/////////////Fonctions 1 capteur/////////////////////////////
double Ultrason_Read(int choix_capteur){ //Lit la distance lu par un des 4 capteurs HC-SR04
  switch (choix_capteur){
    case 0: return hc_front.dist();
    case 1: return hc_right.dist();
    case 2: return hc_left.dist();
    case 3: return hc_back.dist();
  }
}

int Ultrason_Indication(int choix_capteur){  //Indique un degré d'éloignement de l'obstacle entre 0 et 3: 0-erreur 1<20cm 2<50cm 3<100cm 4>100cm
  double distance = Ultrason_Read(choix_capteur);
  if (distance<=0){
    if(++erreur_ultrason>lim_err_HC) { ultrason_ERREUR(); }
    else return 0;
  }
  else if (distance<20)  { return 1; }
  else if (distance<50)  { return 2; }
  else if (distance<100) { return 3; }
  else                   { return 4; }
}
//////////////////////////////////////////////////////////////


/////////////Fonctions 4 capteurs/////////////////////////////
double* Ultrason_All_Read(){ //Ne pas oublier de supprimer l'allocation mémoire distance !
  double* distance= new double[4];
  distance[0]=Ultrason_Read(front);
  delay(measure_time);
  distance[1]=Ultrason_Read(right);
  delay(measure_time);
  distance[2]=Ultrason_Read(left); 
  delay(measure_time);
  distance[3]=Ultrason_Read(back);  
  return distance;
}

int* Ultrason_All_Indication(){ //Ne pas oublier de supprimer l'allocation mémoire indication !
  int* indication=new int[4];
  double* distance=Ultrason_All_Read();
  for (int i=0; i<=3; i++){
    if (distance[i]<=0){
      if(++erreur_ultrason>lim_err_HC) { ultrason_ERREUR(); }
      else indication[i]=0;
    }
    else if (distance[i]<20)  { indication[i]=1; }
    else if (distance[i]<50)  { indication[i]=2; }
    else if (distance[i]<100) { indication[i]=3; }
    else                      { indication[i]=4; }
  }
  delete distance; //Suppression allocation mémoire générée par Ultrason_All_Read();
  return indication;
}
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

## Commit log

2022-05-18 Contenu actuel du proejt Culture Maker
    [Plaque Face Arrière.stl, Plaque Face Avant.stl, Plaque Latérale Droite.stl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]
2022-05-29 update with circuits
